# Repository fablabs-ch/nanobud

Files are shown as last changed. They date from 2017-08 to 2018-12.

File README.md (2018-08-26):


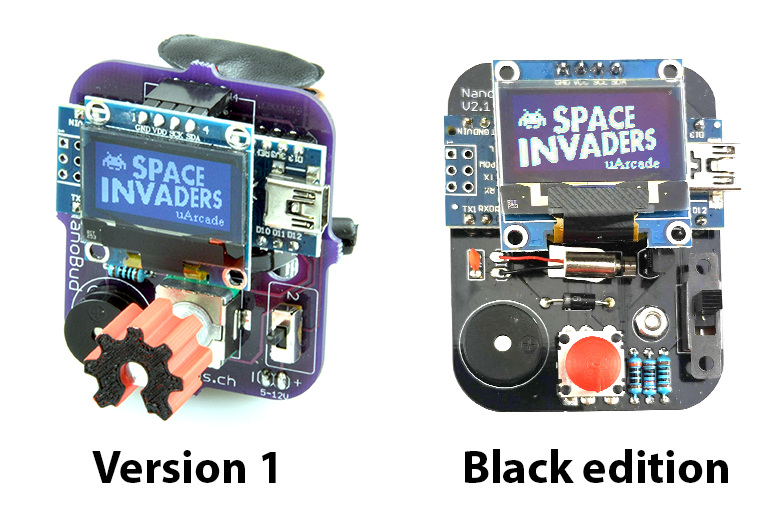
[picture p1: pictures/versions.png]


# Description
NanoBud is a simple electronic project created for workshops into FabLabs.
Basically this project is provided with "Space Invaders" retro game made by makestuffordie.
With simple electronic components you can make some great stuffs.
But you can use it not only for gaming. 
Per example, replace the rotary encoder by a temperature sensor, load the suitable arduino sketch, then you have a beautiful portable weather station!

With this project you can do a workshop and show people how to assembly electronic components and get perfect welds. 
Please visit the wiki to get the workshop kit. -> [Wiki](https://github.com/fablabs-ch/nanobud/wiki)

But not only, if you want go further and make different kind of workshops, here some quick ideas:
- How to load and programm Arduino boards
- How to manage oled screen.
- Design your own case for 3D print or 2D Lasercut.

As you understood, the only limit is your creativity. :-)

Enjoy and don't hesitate to share your experiences.

# Hardware
## Material
*Version 1*
- 1x Rotary encoder
- 1x Arduino Nano
- 1x OLED screen 0.96" 128x64pix
- 1x micro switch
- 1x 9V Battery
- 1x 9V  to wire adapter
- 1x Buzzer
- 1x Resistor 100 Ohms
- 1x Female pin header	1x4

*Black edition*
- 1x Female pin header	1x4
- 1x Arduino Nano
- 1x OLED screen 0.96" 128x64pix
- 1x micro switch
- 1x 9V Battery
- 1x 9V  to wire adapter
- 1x Buzzer
- 1x Resistor 100 Ohms
- **1x Capacitor 100pF**
- **1x Shotkky diode	1N5819**
- **1x Vibrator	3.3V**
- **1x Resistor	300 Ohms**
- **1x Resistor	10k**
- **1x MOSFET	BS170**
- **1x Mini Joystick**	
- **1x Battery holder 9V**
- **1x ScrewVis M2.5 x8mm**	
- **1 PCB black**

# Software
The version 1 is the sketch from makestuffordie
Black edition need the software made for. sotware/nanobud. It will manage the vibrator and the joystick

Improvements or other applications would be appreciated. Don't hesitate to share it!
Don't hesitate participate to the project.

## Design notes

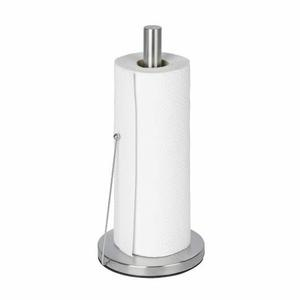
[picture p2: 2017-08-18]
pictures/wiki/clean_paper.png

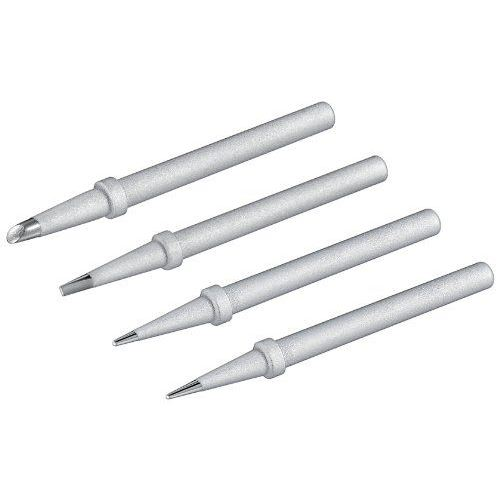
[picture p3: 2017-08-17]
pictures/wiki/welding_tip_1.png

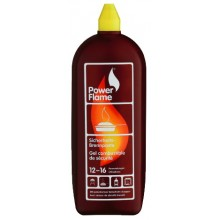
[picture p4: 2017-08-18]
pictures/wiki/alcool.png

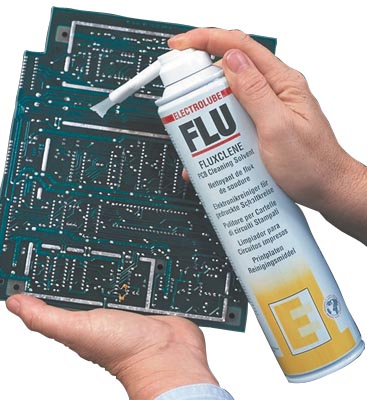
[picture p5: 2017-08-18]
pictures/wiki/flux_spray.png

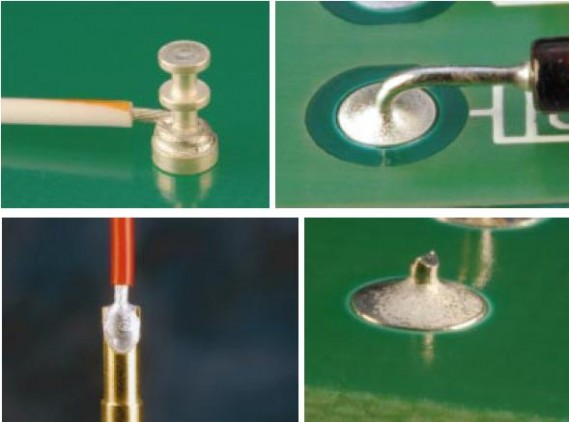
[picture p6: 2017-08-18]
pictures/wiki/good_weld2.png

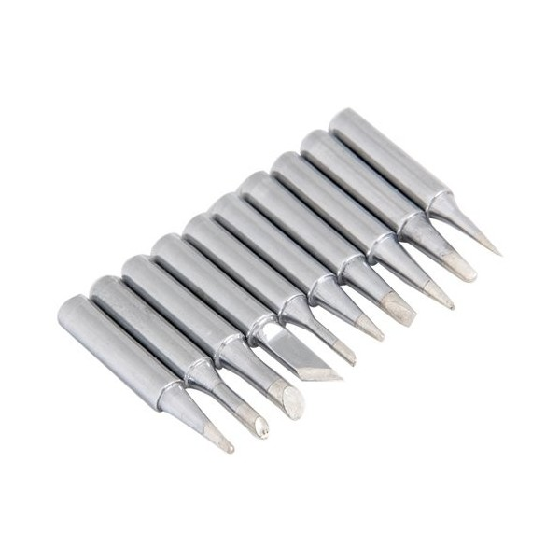
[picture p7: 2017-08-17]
pictures/wiki/welding_tip_4.png

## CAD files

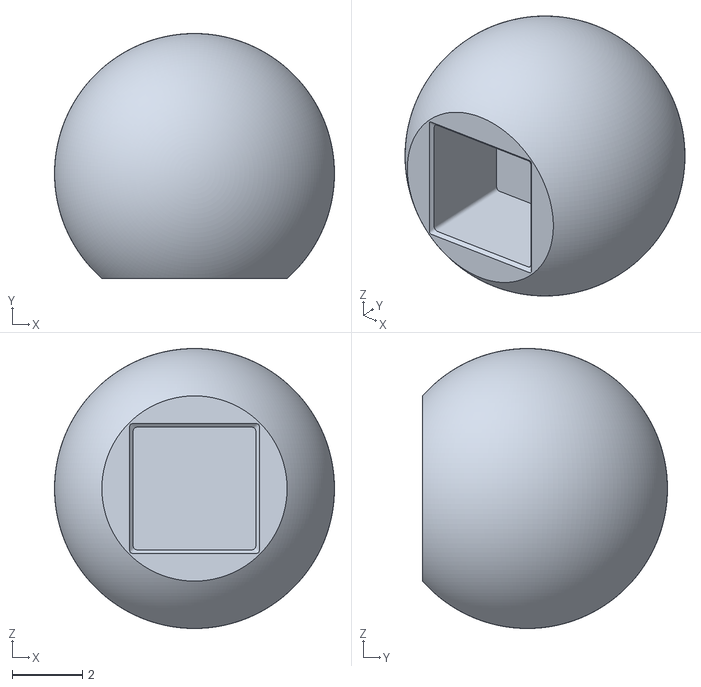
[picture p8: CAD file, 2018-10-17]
hardware/joystick_blackedition.stl
8.00 x 7.00 x 8.00

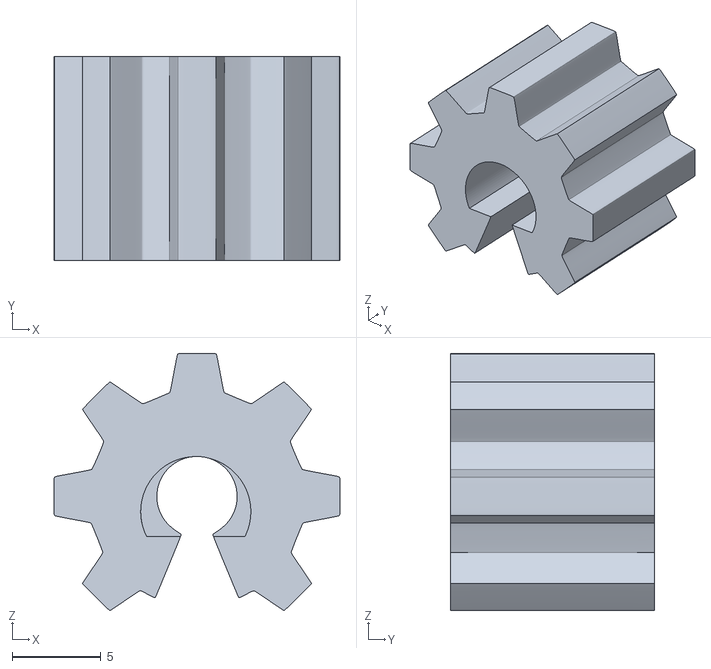
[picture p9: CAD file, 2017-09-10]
hardware/open_knob.stl
16.1 x 11.5 x 14.5

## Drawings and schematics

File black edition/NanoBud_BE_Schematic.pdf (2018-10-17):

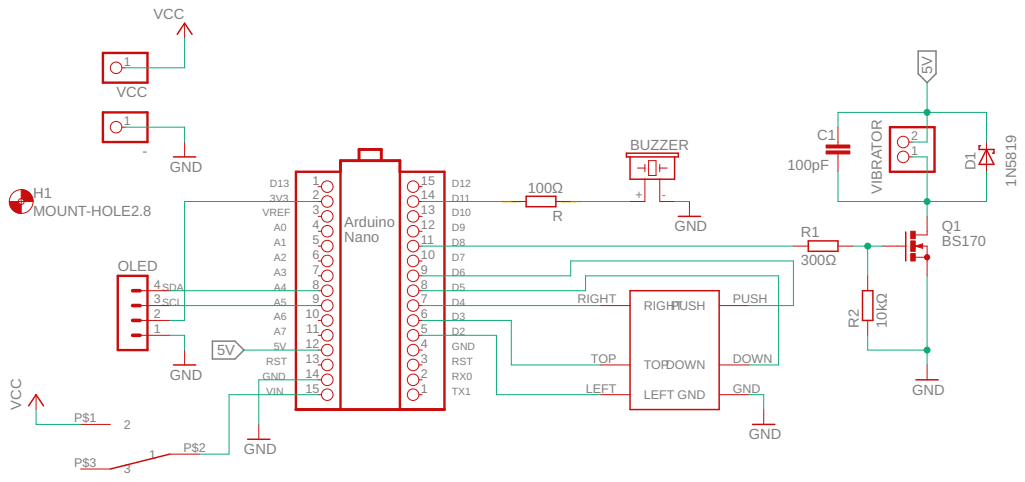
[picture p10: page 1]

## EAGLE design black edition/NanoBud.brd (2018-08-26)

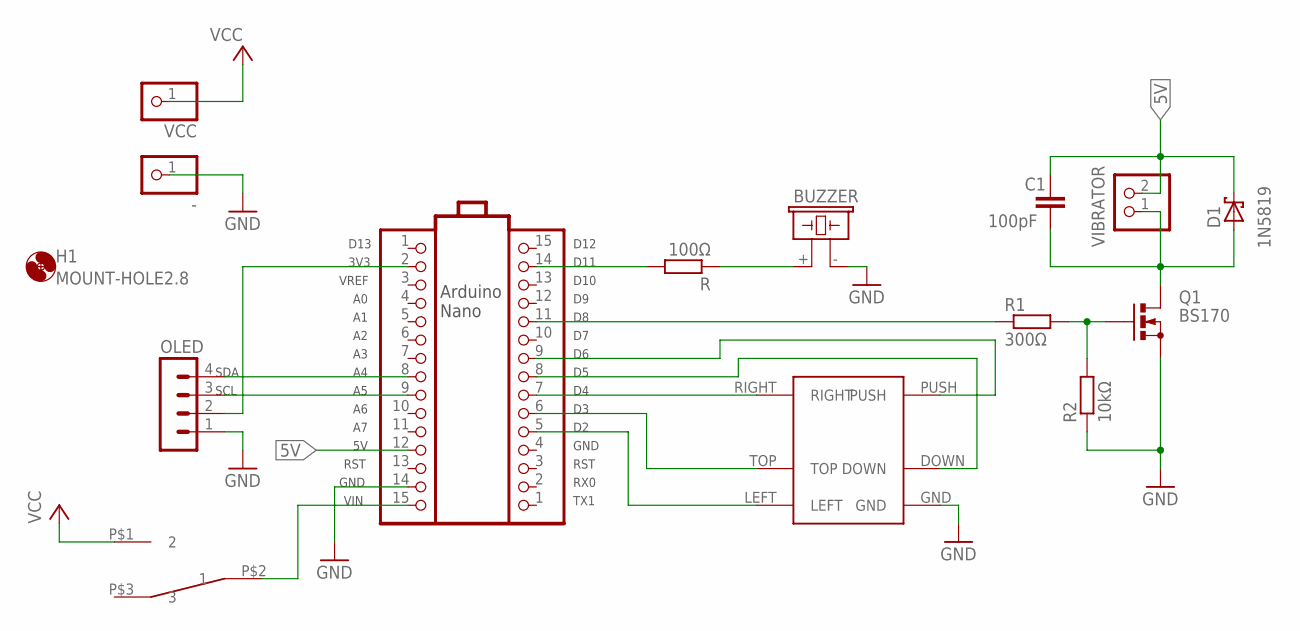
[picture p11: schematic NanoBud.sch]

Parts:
-: PINHD-1X1; 1X01
BUZZER: F/CM12P
C1: 100pF; C2.5-2
D1: BAT49; DO41-10
H1: MOUNT-HOLE2.8; 2,8
OLED: MA04-1
Q1: BS170; SOT54E
R: 100Ω; 0204/7
R1: 300Ω; 0204/7
R2: 10kΩ; 0204/7
SV1, SV2: PINHD-1X15; 1X15
U$1: SWITCHCHINOIS
U$2: MOMENTARYBUTTON
VCC: PINHD-1X1; 1X01
VIBRATOR: PINHD-1X2; 1X02

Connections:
3V3: OLED.2, SV2.2
5V: C1.1, D1.C, SV2.12, VIBRATOR.2
GND: -.1, BUZZER.- (2), OLED.1, Q1.S, R2.1, SV2.14, U$2.GND
unnamed: SV1.5, U$2.LEFT
unnamed: SV1.6, U$2.TOP
unnamed: SV1.7, U$2.RIGHT
unnamed: SV1.8, U$2.DOWN
unnamed: SV1.9, U$2.PUSH
unnamed: OLED.3, SV2.9
unnamed: OLED.4, SV2.8
unnamed: BUZZER.+ (1), R.1
unnamed: R.2, SV1.14
unnamed: SV2.15, U$1.P$2 (1)
unnamed: R1.1, SV1.11
unnamed: Q1.G, R1.2, R2.2
unnamed: C1.2, D1.A, Q1.D, VIBRATOR.1
VCC: U$1.P$1 (2), VCC.1

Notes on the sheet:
SDA
SCL
D13
3V3
VREF
RST
GND
VIN
TX1
RX0
D10
D11
D12
Arduino Nano
1N5819

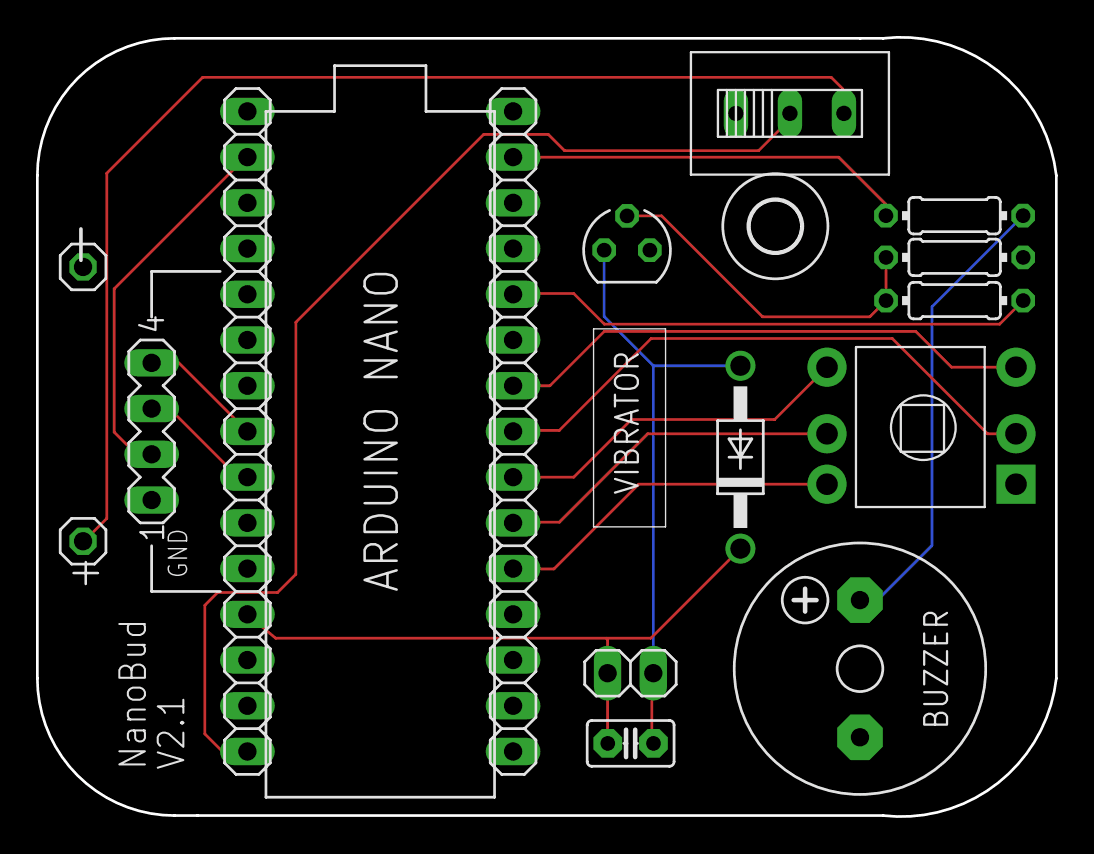
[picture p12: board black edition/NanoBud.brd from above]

Board: 2 copper layers, 56.6 x 43.3 mm, 16 parts (0 on the bottom side), 17 nets.

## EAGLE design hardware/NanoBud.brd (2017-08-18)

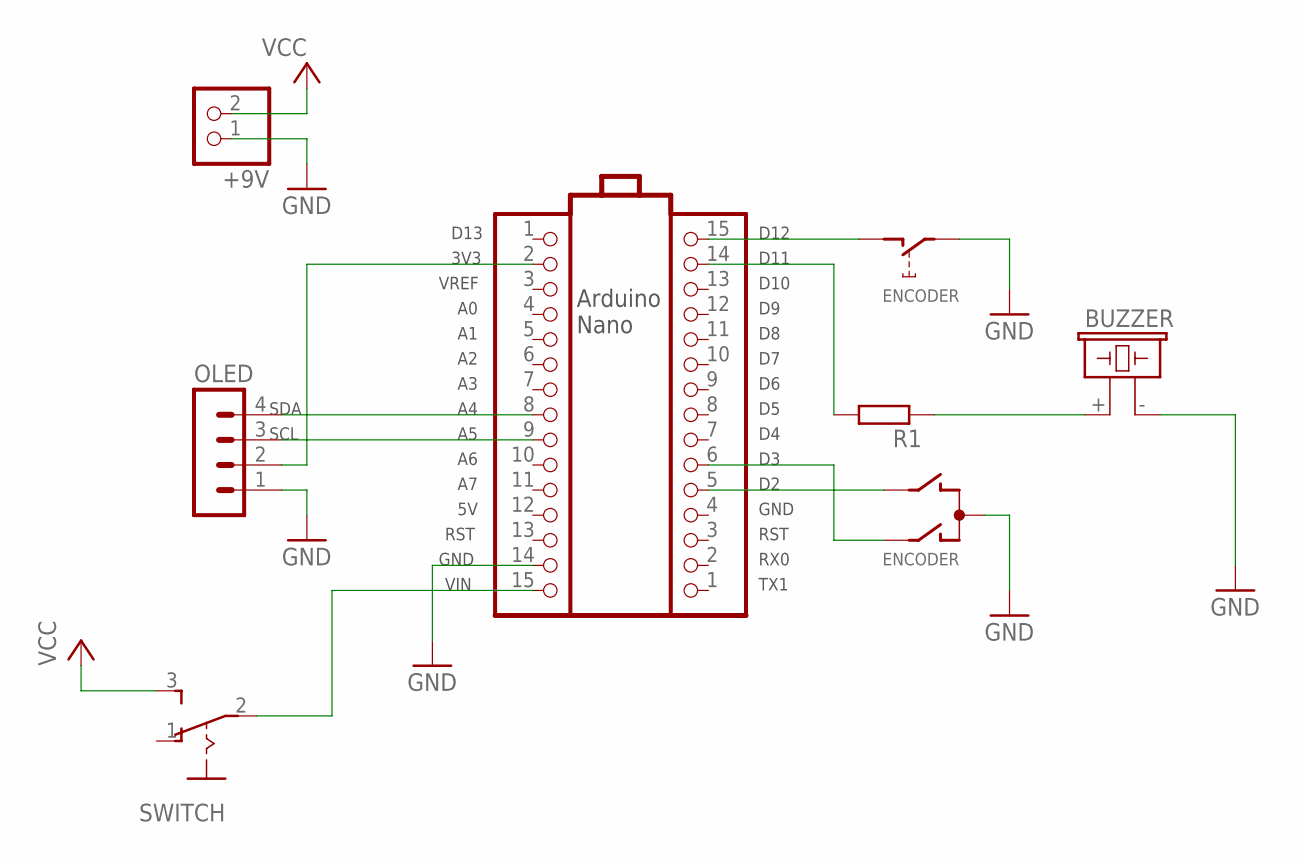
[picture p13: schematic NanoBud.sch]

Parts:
+9V: PINHD-1X2; 1X02
BUZZER: F/CM12P
ENCODER: EC12E_SW; ALPS_EC12E_SW
OLED: MA04-1
R1: R0204/7; 0204/7
SV1, SV2: PINHD-1X15; 1X15
SWITCH: M251

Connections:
GND: +9V.1, BUZZER.- (2), ENCODER.C, ENCODER.E (2), OLED.1, SV2.14
unnamed: ENCODER.A, SV1.6
unnamed: ENCODER.D (1), SV1.15
unnamed: ENCODER.B, SV1.5
unnamed: OLED.2, SV2.2
unnamed: OLED.3, SV2.9
unnamed: OLED.4, SV2.8
unnamed: BUZZER.+ (1), R1.1
unnamed: R1.2, SV1.14
unnamed: SV2.15, SWITCH.2
VCC: +9V.2, SWITCH.3 (S)

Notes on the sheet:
SDA
SCL
D13
3V3
VREF
RST
GND
VIN
TX1
RX0
D10
D11
D12
Arduino Nano

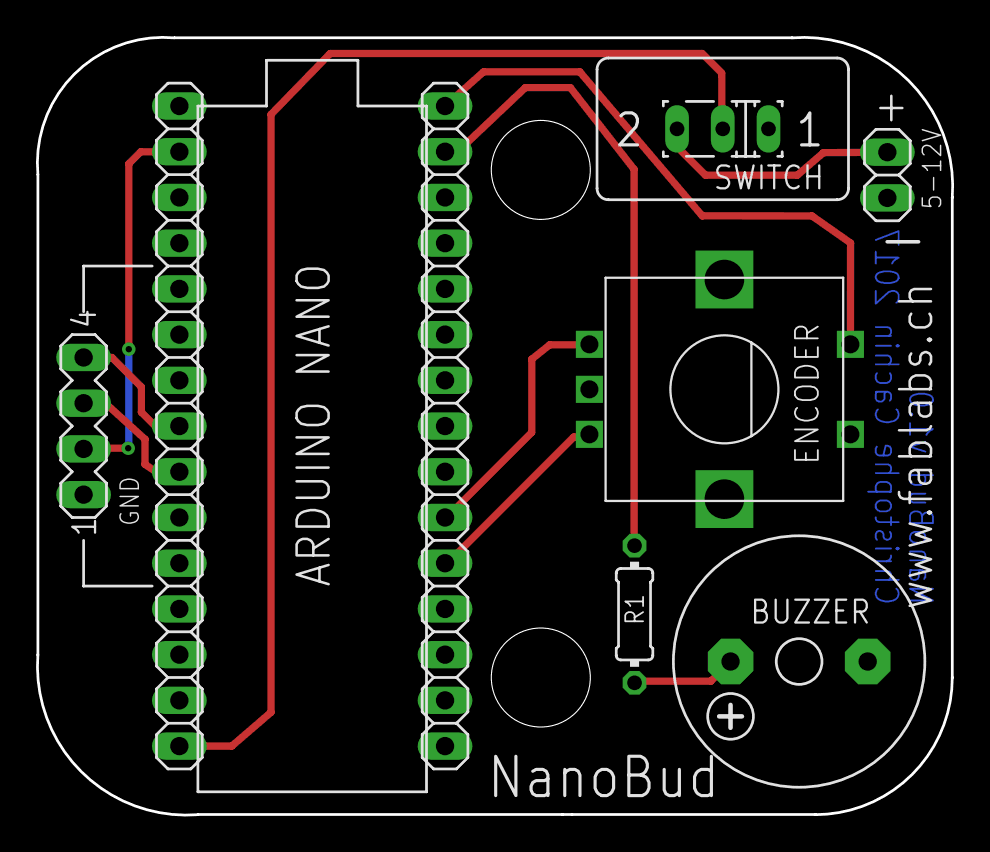
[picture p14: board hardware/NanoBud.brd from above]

Board: 2 copper layers, 50.9 x 43.2 mm, 8 parts (0 on the bottom side), 11 nets.

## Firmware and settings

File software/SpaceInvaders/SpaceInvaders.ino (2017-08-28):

//               ___                            __
//       __  __ /   |   _____ _____ ____ _ ____/ /___
//      / / / // /| |  / ___// ___// __ `// __  // _ \
//     / /_/ // ___ | / /   / /__ / /_/ // /_/ //  __/
//     \__,_//_/  |_|/_/    \___/ \__,_/ \__,_/ \___/
//
//              Created by Yair Kapach 2015
//        For uArcade build details, please visit:
//         http://www.youtube.com/user/microstrat
//           http://makestuffordie.blogspot.com/
//
//  You may do whatever you want with this code, as long as:
//    a. share it and keep it FREE.
//    b. keep the original credits.

#include <U8glib.h>
#include "pitches.h"

static const uint32_t splash [] U8G_PROGMEM = {0,0,0,0,0,0,0,0,0,0,0,0,0,0,0,0,0,0,0,0,0,0,0,0,0,7936,0,0,0,536362880,520095680,127,25171968,0x7FF8FFE0,0x3FC007C0,127,25171968,0x7FF87FE0,0x3FE00FE0,127,6316032,0xF8F871F0,0x3FF00FE0,7,6316032,0xF8F831F0,838344672,7,33552384,0xF0F811F0,7872480,7,33552384,0xF0F801F0,3677936,7,0x79F9E00,0xF0F807F0,3940080,119,0x79F9E00,0xF8F81FF0,3947640,127,536870784,0xFCF83FF0,3947640,127,536870784,0x7FF8FFE0,3947640,127,436205952,0x7FF9FF80,3963000,7,436205952,536475648,7895164,7,427825536,0xF9F000,821592060,7,427825536,0xF9F000,0x3FF87FFC,7,7987200,0xF9F000,0x3FF0FFFC,127,7987200,0xF9F1E0,0x3FE0F03E,127,0,0xF8F9F0,0x3FC0F03E,127,0,0xF8FFF0,520220734,1,0,0xF87FF0,4159,3145728,0,0xF03FC0,0,8128496,0,384,0xF8080000,8265715,0,0,0xFC2FF004,8265715,0,0xC1F00000,0xF83FF00F,2571507,0,0xC0F007CC,947908623,474224,0x801E0000,0xC0F807CF,947712031,473200,0x801F07C0,0xE0FC0F8F,955281439,2047088,0x807F0FC0,0xE0FC1F8F,955314239,8339056,0x80FF0FC0,0xE0781F8F,0xB9E0F03F,0xFE1FF3,0x81FF0FC0,0xF07C1F0F,0xF9E0F03D,0xFC0FF3,0x81FF0FC0,0xF07E3F0F,0xF9E0F03D,0xE00FF3,0x81FF0FC0,0xF03E3F0F,0xF9E0F078,0xE007F3,0x7FF0FC0,0xF83E3E0F,971042936,0xE20F70,0xFFF0FC0,0xF83E3E0F,954265720,0xF60F70,536809408,0x781F7E1F,955314416,8330864,0x3F9F0FC0,0x7C1F7C1F,955314416,4136048,0x3F9F0FC0,0xFC1FF81F,0xF878F0FF,3947635,0x3F1F0FC0,0xFC0FF81F,0xF87CF1FF,14451,0xFE1F0FC0,0xFC0FF01F,0xF83FF1FF,51,0xFC1F0FC0,0xFE0FF01F,941617632,0,0xF81F0FC0,0x3E0FF01F,0xFF1E0,0,0xF01F0FC0,0x3E07F01F,5088,0,0xF01F0FC0,0x3E07E01F,0,0,0xE03F0FC0,520347679,0,0,0xC03F0FC0,245791,16777216,524288,0x803F0FC0,31,16777216,786432,4132800,15,41943040,524288,4132800,0,0x82866000,25889906,462784,0,0xC4444000,38572617,1984,0,0x87C44000,63478792,0,0,0x88244000,4755976,0,0,0x882E4000,39621192,0,0,0xDC758000,25902129,0,0,0,0,0,0,0,0,0,0,0,0,0,0,0,0};
static const uint16_t monsters[] U8G_PROGMEM = {0x0600,0x0F00,0x1F80,0x36C0,0x3FC0,0x0900,0x1680,0x2940,0x0600,0x0F00,0x1F80,0x36C0,0x3FC0,0x0900,0x1080,0x0900,0x2080,0x9120,0xBFA0,0xEEE0,0x7FC0,0x3F80,0x2080,0x4040,0x2080,0x1100,0x3F80,0x6EC0,0xFFE0,0xBFA0,0xA0A0,0x1B00,0x0E00,0x7FC0,0xFFE0,0xCE60,0xFFE0,0x3F80,0x6EC0,0xC060,0x0E00,0x7FC0,0xFFE0,0xCE60,0xFFE0,0x3F80,0x6EC0,0x3180};

const int BUZZER_PIN =11;

//U8GLIB_SSD1306_128X64 u8g(13, 11, 10, 9);  // SW SPI Com: SCK = 13, MOSI = 11, CS = 10, d/c A0 = 9
U8GLIB_SSD1306_128X64 u8g(U8G_I2C_OPT_NONE); // I2C: SCL=A5,SDA=A4

const int screenW = 128, screenH = 64;
enum GameState { GAME_NORMAL, GAME_WIN, GAME_OVER } g_gameState;

// encoder debounce was taken from: http://playground.arduino.cc/Main/RotaryEncoders
enum EncoderPins {  ENCODER_PIN_LEFT = 2, ENCODER_PIN_RIGHT = 3, ENCODER_PIN_FIRE = 12};

volatile unsigned char encoderPos = 127;  // a counter for the dial
unsigned int lastReportedPos = 1;         // change management
static boolean rotating = false;          // debounce management
int lastPress = HIGH;
int debounce = 20;
int lastTime = 0;
int state = LOW;

// interrupt service routine vars
boolean A_set = false;
boolean B_set = false;

bool checkBtn() {
  rotating = true;  // reset the debouncer

  if (lastReportedPos != encoderPos) {
    lastReportedPos = encoderPos;
  }
  int reading = digitalRead(ENCODER_PIN_FIRE);

  if (reading != lastPress) {
    lastTime = millis(); // reset the debouncing timer
  }

  if ((millis() - lastTime) > debounce) {
    if (reading != state) {
      state = reading;
      tone(BUZZER_PIN,2093,50);
      delay(20);
      if (state == LOW) {
        return true;
      }
    }
  }
  lastPress = reading;
  return false;
}

void(* resetFunc) (void) = 0;

// notes in the melody:
int melody[] = {
  NOTE_C4, NOTE_G3, NOTE_G3, NOTE_A3, NOTE_G3, 0, NOTE_B3, NOTE_C4
};

// note durations: 4 = quarter note, 8 = eighth note, etc.:
int noteDurations[] = {
  4, 8, 8, 4, 4, 4, 4, 4
};


void doEncoderA() { // Interrupt on A changing state
  // debounce
  if (rotating)
    delay(1);  // wait a little until the bouncing is done

  // Test transition, did things really change?
  if (digitalRead(ENCODER_PIN_RIGHT) != A_set) {  // debounce once more
    A_set = !A_set;
    // adjust counter + if A leads B
    if (A_set && !B_set && encoderPos != 0xff) {
      encoderPos++;
    }
    rotating = false;  // no more debouncing until loop() hits again
  }
}

void doEncoderB() { // Interrupt on B changing state, same as A above
  if (rotating)
    delay(1);
  if (digitalRead(ENCODER_PIN_LEFT) != B_set) {
    B_set = !B_set;
    if (B_set && !A_set && encoderPos != 0) {  //  adjust counter - 1 if B leads A
      encoderPos--;
    }
    rotating = false;
  }
}

void setupEncoder() {
  pinMode(ENCODER_PIN_RIGHT, INPUT);
  pinMode(ENCODER_PIN_LEFT, INPUT);
  pinMode(ENCODER_PIN_FIRE, INPUT);
  digitalWrite(ENCODER_PIN_RIGHT, HIGH);
  digitalWrite(ENCODER_PIN_LEFT, HIGH);
  digitalWrite(ENCODER_PIN_FIRE, HIGH);
  attachInterrupt(0, doEncoderA, CHANGE);
  attachInterrupt(1, doEncoderB, CHANGE);
}

class Lasers {
public:
  enum { LASER_H = 3, MAX_LASERS = 4, INACTIVE_LASER = 0xff };

  Lasers() { reset(); }

  void reset() {
    memset(_y, INACTIVE_LASER, MAX_LASERS);
    //_lastStep = millis();
  }

  void add(uint8_t x, uint8_t y) {
    for (int i = 0; i < MAX_LASERS; i++) {
      if (_y[i] == INACTIVE_LASER) {
        _y[i] = y;
        _x[i] = x;
        break;
      }
    }
  }

  void draw() {
    for (int i = 0; i < MAX_LASERS; i++) {
      uint8_t y = _y[i];
      if (y != INACTIVE_LASER) {
        u8g.drawVLine(_x[i], _y[i], LASER_H);
      }
    }
  }

  void step() {
//    if (millis() - _lastStep < 50)
//      return;
//
//    _lastStep = millis();

    for (int i = 0; i < MAX_LASERS; i++) {
      uint8_t y = _y[i];
      if (y != INACTIVE_LASER) {
        if (y < 2) {
          y = INACTIVE_LASER;
        } else {
          y -= 2;
        }
      }
      _y[i] = y;
    }
  }

  uint8_t _y[MAX_LASERS];
  uint8_t _x[MAX_LASERS];
//  unsigned long _lastStep;
};

Lasers lasers;

class PlayerShip {
public:
  enum { SHIP_RAD = 6, SHIP_W = SHIP_RAD * 2 + 1, SHIP_H = 6, SHIP_Y = screenH - 1 - SHIP_H };

  PlayerShip() : _x(screenW / 2) {}

  void draw() {
    u8g.drawHLine(_x - 1, SHIP_Y, 3);
    u8g.drawHLine(_x - 1, SHIP_Y + 1, 3);
    u8g.drawHLine(_x - (SHIP_RAD - 1), SHIP_Y + 2, SHIP_W - 2);
    u8g.drawHLine(_x - SHIP_RAD, SHIP_Y + 3, SHIP_W);
    u8g.drawHLine(_x - SHIP_RAD, SHIP_Y + 4, SHIP_W);
    u8g.drawHLine(_x - SHIP_RAD, SHIP_Y + 5, SHIP_W);
  }

  void step() {
    const bool fire = checkBtn();
    _x = screenW / 2 + (encoderPos - 127) * 4;

    if (_x - SHIP_RAD < 0) _x = SHIP_RAD;
    if (_x + SHIP_RAD >= screenW) _x = screenW - SHIP_RAD - 1;
    if (fire) lasers.add(_x, SHIP_Y - Lasers::LASER_H);
  }
  int _x;
};

class Monsters {
public:
  enum { SPEED = 300 };
  enum { BLANK_IDX = 6 };
  enum { MAX_COLS = 8, MAX_ROWS = 4, MON_WIDTH = 16, MON_HEIGHT = 8, MON_HMARGIN = 1 };

  Monsters(const int x, const int y, const int width, const int height, const uint8_t *data) {
    _x = x;
    _y = y;
    _left = 0;
    _right = width * MON_WIDTH;
    _bottom = height * (MON_HEIGHT + MON_HMARGIN);
    _dx = 1;
    _width = width;
    _height = height;
    _currSprite = 0;
    _lastUpdate = millis();
    memcpy(_data, data, MAX_COLS * MAX_ROWS);
  }

  void step() {
    if (millis() - _lastUpdate >= SPEED) {
      _lastUpdate = millis();
      _currSprite ^= 1;
      _x += _dx;
      if (_x + _left < 0) {
        _x = -_left;
        _dx = -_dx;
        _y++;
      }
      if (_x + _right >= screenW) {
        _x = screenW - _right - 1;
        _dx = -_dx;
        _y++;
      }
    }
    if (_y + _bottom >= PlayerShip::SHIP_Y) {
      //_y = 0;
      g_gameState = GAME_OVER;
    }
  }
  void draw() {
    for (int i = 0; i < _height; i++) {
      for (int j = 0; j < _width; j++) {
        const int idx = _data[j + i * MAX_COLS] + _currSprite;
        if (idx < BLANK_IDX) {
          u8g.drawXBMP(_x + j * MON_WIDTH, _y + i * (MON_HEIGHT + MON_HMARGIN), MON_WIDTH, MON_HEIGHT, (unsigned char*) (monsters + idx * MON_WIDTH / 2));
        }
      }
    }
  }
  void hitTest() {
    bool hit = false;
    for (int i = 0; i < Lasers::MAX_LASERS; i++) {
      // quick fallbacks
      uint8_t y = lasers._y[i];
      if ((y == Lasers::INACTIVE_LASER) || (y + Lasers::LASER_H < _y) || (y >= _y + _bottom))
        continue;

      uint8_t x = lasers._x[i];
      if ((x < _x + _left) || (x >= _x + _right))
        continue;

      if (((x - _x) & 0xf) > 12) // hack
        continue;

      int col = (x - _x) / (MON_WIDTH); //& 0xf; // hack mod(ship width)
      int row = (y - _y) / (MON_HEIGHT + MON_HMARGIN);

      if (_data[col + row * MAX_COLS] >= BLANK_IDX)
        continue;

      _data[col + row * MAX_COLS] = BLANK_IDX;
      lasers._y[i] = 0xff;
      hit = true;
      tone(BUZZER_PIN,523,50);
    }

    if (!hit) {
      return;
    }

    int c0 = _width - 1, c1 = 0;
    int r1 = 0;

    for (int i = 0; i < _height; i++) {
      for (int j = 0; j < _width; j++) {
        if (_data[j + i * MAX_COLS] < BLANK_IDX) {
          c0 = min(c0, j);
          c1 = max(c1, j);
          r1 = max(r1, i);
        }
      }
    }
    if (c0 > c1) {
      g_gameState = GAME_WIN;
      return;
    }
    _left = c0 * MON_WIDTH;
    _right = (c1 + 1) * MON_WIDTH;
    _bottom = (r1 + 1) * (MON_HEIGHT + MON_HMARGIN);
  }

  unsigned long _lastUpdate;
  uint8_t _data[MAX_COLS * MAX_ROWS];
  int _width;
  int _height;
  int _x;
  int _y;
  int _left;
  int _right;
  int _bottom;
  int _dx;
  uint8_t _currSprite;
};

const uint8_t level_0[] = { 0, 0, 0, 0, 0, 0, 0xff, 0xff,
                            2, 2, 2, 2, 2, 2, 0xff, 0xff,
                            4, 4, 4, 4, 4, 4, 0xff, 0xff,
                            4, 4, 4, 4, 4, 4, 0xff, 0xff};

Monsters mon(0, 0, 6, 4, level_0);
PlayerShip player;

void setup(void) {
  u8g.setDefaultForegroundColor();
  u8g.setFont(u8g_font_unifont);
  setupEncoder();

  g_gameState = GAME_NORMAL;

  do {
    u8g.firstPage();
    do {
     u8g.drawXBMP(0, 0, screenW, screenH, (const uint8_t*) splash);
    } while (u8g.nextPage());
  } while (digitalRead(ENCODER_PIN_FIRE) == HIGH);
}

void loop(void) {
  if (g_gameState == GAME_NORMAL) {
    u8g.firstPage();
    do {
      mon.draw();
      player.draw();
      lasers.draw();
    } while (u8g.nextPage());

    player.step();
    mon.step();
    lasers.step();
    mon.hitTest();
  } else {
    u8g.firstPage();
    do {
      if (g_gameState == GAME_OVER) {
        u8g.drawStr(26, 33, "Game Over");
      } else {
        u8g.drawStr(26, 33, "YOU ROCK!!!");

          for (int thisNote = 0; thisNote < 8; thisNote++) {

          // to calculate the note duration, take one second divided by the note type.
          //e.g. quarter note = 1000 / 4, eighth note = 1000/8, etc.
          int noteDuration = 1000 / noteDurations[thisNote];
          tone(11, melody[thisNote], noteDuration);

          // to distinguish the notes, set a minimum time between them.
          // the note's duration + 30% seems to work well:
          int pauseBetweenNotes = noteDuration * 1.30;
          delay(pauseBetweenNotes);
          // stop the tone playing:
          noTone(8);
        }
        resetFunc();
      }
    } while (u8g.nextPage());
  }
}

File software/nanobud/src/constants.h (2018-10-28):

#define GAME_SPACE_INVADERS 1
#define GAME_SNAKE 2

// Choose your game
#define GAME GAME_SNAKE


#define PIN_VIBRATOR 8
#define PIN_BUZZER 11
#define PIN_CENTER 6
#define PIN_RIGHT 4
#define PIN_LEFT 2
#define PIN_TOP 3
#define PIN_BOTTOM 5

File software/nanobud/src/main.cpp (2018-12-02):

#include <Arduino.h>
#include <U8g2lib.h>

#include "constants.h"
#include <input.h>
#include <sound.h>
#include <vibrator.h>

#if GAME == GAME_SPACE_INVADERS
    #include <game_spaceinvaders.h>
#elif GAME == GAME_SNAKE
    #include <game_snake.h>
#endif

U8G2_SSD1306_128X64_NONAME_2_HW_I2C display(U8G2_R0); // I2C: SCL=A5,SDA=A4

Vibrator vibrator(PIN_VIBRATOR);
Sound sound(PIN_BUZZER);

#if GAME == GAME_SPACE_INVADERS
    GameSpaceInvaders game(&display, &sound, &vibrator);
#elif GAME == GAME_SNAKE
    GameSnake game(&display, &sound, &vibrator);
#endif

Input input(PIN_CENTER, PIN_LEFT, PIN_RIGHT, PIN_TOP, PIN_BOTTOM, &game);

unsigned long lastLoop = 0;

void setup()
{
    Serial.begin(115200);

    Serial.println("start");
    display.begin();
    input.init();
    sound.init();
    vibrator.init();
    game.init();
}

void loop()
{
    unsigned long nowMs = millis();
    unsigned long dtMs = nowMs - lastLoop;

    input.loop(nowMs, dtMs);
    sound.loop(dtMs);
    vibrator.loop(dtMs);
    game.loop(nowMs, dtMs);

    lastLoop = nowMs;
}

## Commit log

2017-08-17 Content in progress
    Hardware/Software files
    [NanoBud_PANEL.drl]
2017-08-17 Update
    Readme
    Arduino sketch
2017-08-17 pictures for welding station
2017-08-18 Hardware files
    [NanoBud.brd, NanoBud.sch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]
2017-08-18 dimension update
    [NanoBud.brd]
2017-08-25 Add tone on buzzer
    And reset when game is done
    [uArcade.ino]
2017-08-27 rotary by interrupt
2017-09-10 encoder knob
    [open_knob.stl]
2018-08-16 splash and button
2018-08-22 black edition
    adding:
    - joystick
    - vibrator
    - battery holder
    [NanoBud.brd, NanoBud.sch]
2018-08-22 new picts
    new pictures for black edition and assembly instructions
2018-10-17 Update
    joystick .stl
    new instructions
    [joystick_blackedition.stl]
